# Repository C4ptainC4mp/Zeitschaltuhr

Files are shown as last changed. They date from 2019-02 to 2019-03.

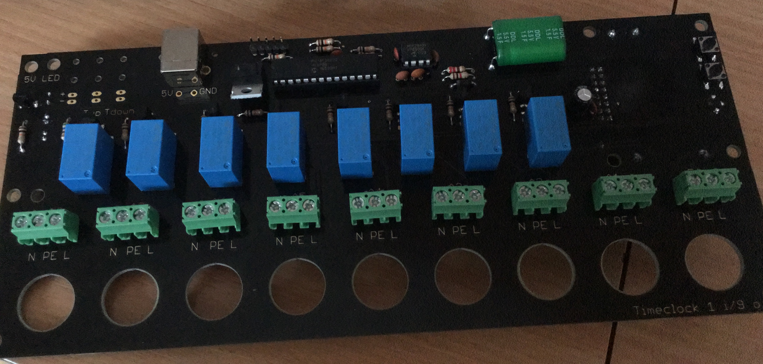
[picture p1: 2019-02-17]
demo/back.jpg

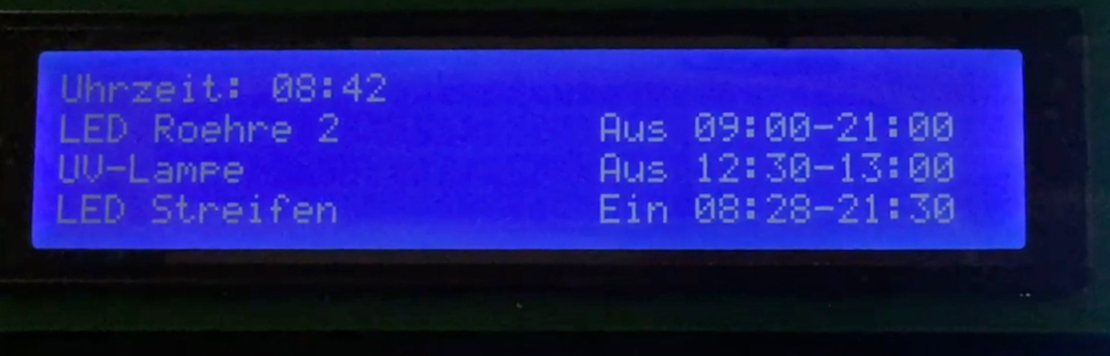
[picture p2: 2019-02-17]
demo/front_LCD.jpg

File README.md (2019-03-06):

# Zeitschaltuhr. 
time switch, supporting 8 AC outputs (10A max) and a 5V DC PWM output (2A max). 

This is a time switch supporting 8 AC outputs and a 5V DC PWM output. It also offers visualization with a LC-Display, configuration by a 2 button interface, a Real-Time-Clock(RTC) powered by a SuperCap and an on-board AC/DC power module.  

The combined switched power of all the AC outputs should not exceed 16A while a single output is limited to 10A. The DC PWM output is limited to 2A by the 15W IRM-15-5 AC/DC power module, more power output might be possible by selecting a better power module and power mosfet.

The current output status is presented by a 4x40 Character LC-Display. The first line shows the current time while the lines 2 to 4 show the outputs. Only 3 outputs are shown at once, it is possible to scroll trough the other outputs by pressing the scroll button.

In case of an blackout, the RTC is powered by a supercap for at least a week.  

It is possible to reconfigure the names and times by scrolling the target output to line 2 and pressing the select button.

The USB-B port is used to power the device while programming and debuging.

MCU: Microchip PIC18F26k22<br />
RTC: Microchip MCP 7940N (7940M also, but without backup power)<br />
LCD: ERM4004SBS-1 (2x KS0066 (HD44780 compatible))<br />

/demo includes a photo of the front and back side of the finished time switch.

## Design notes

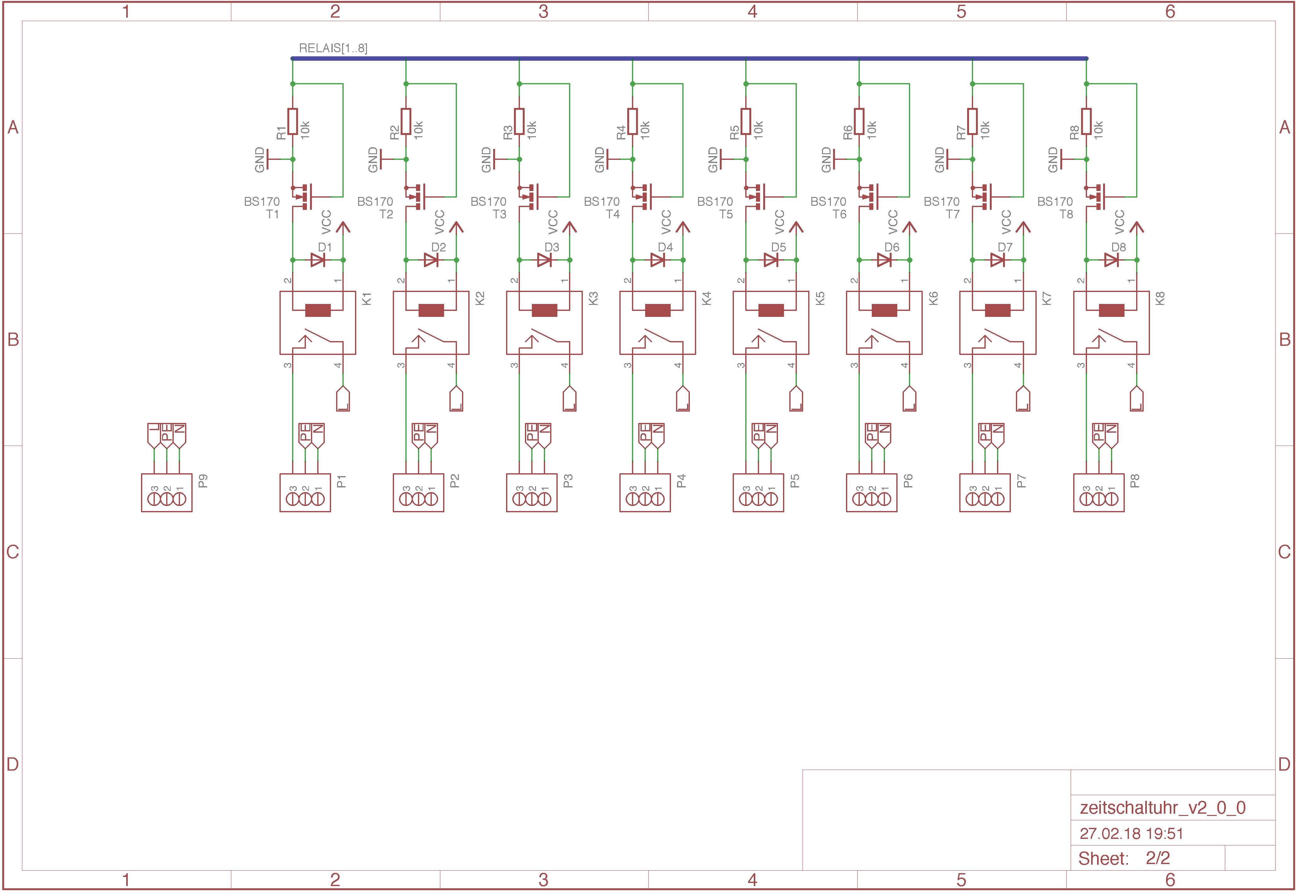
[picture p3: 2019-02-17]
Zeitschaltuhr V2.0.0/schematic_2.png

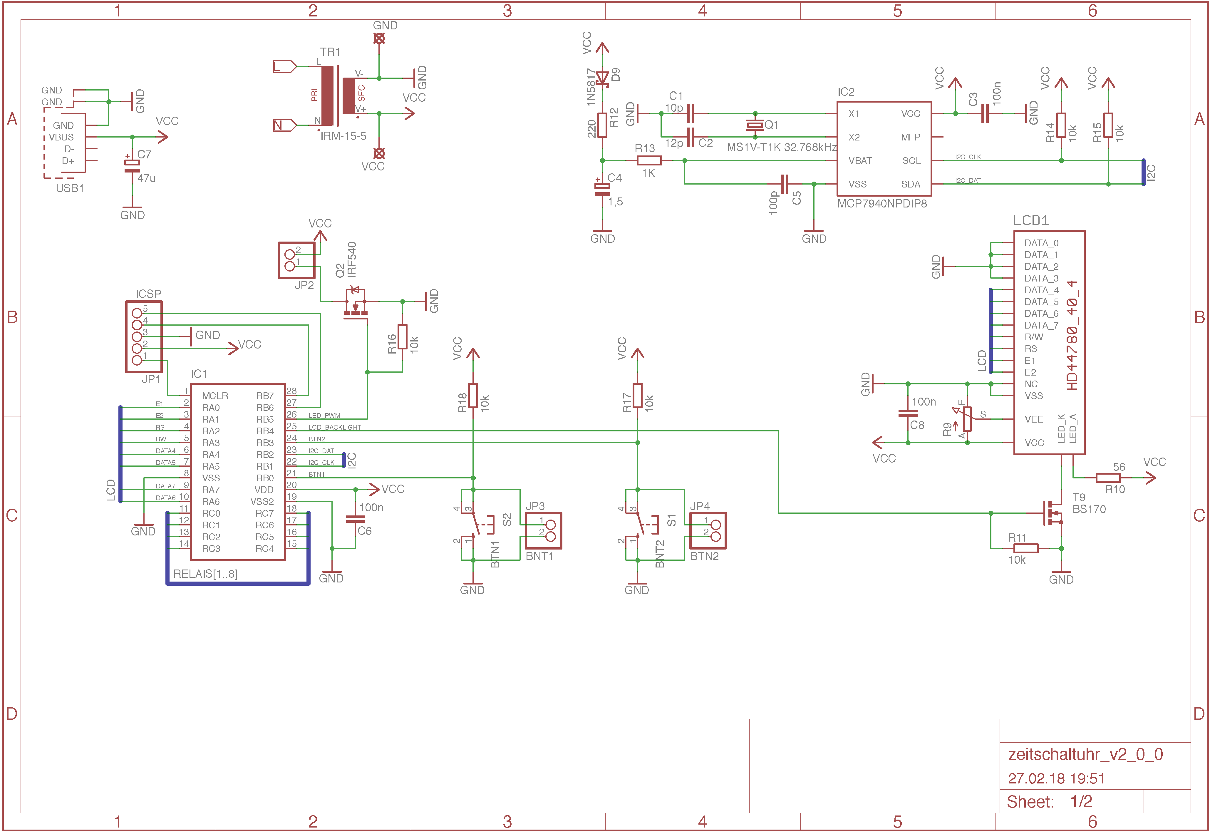
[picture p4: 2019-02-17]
Zeitschaltuhr V2.0.0/schematic_1.png

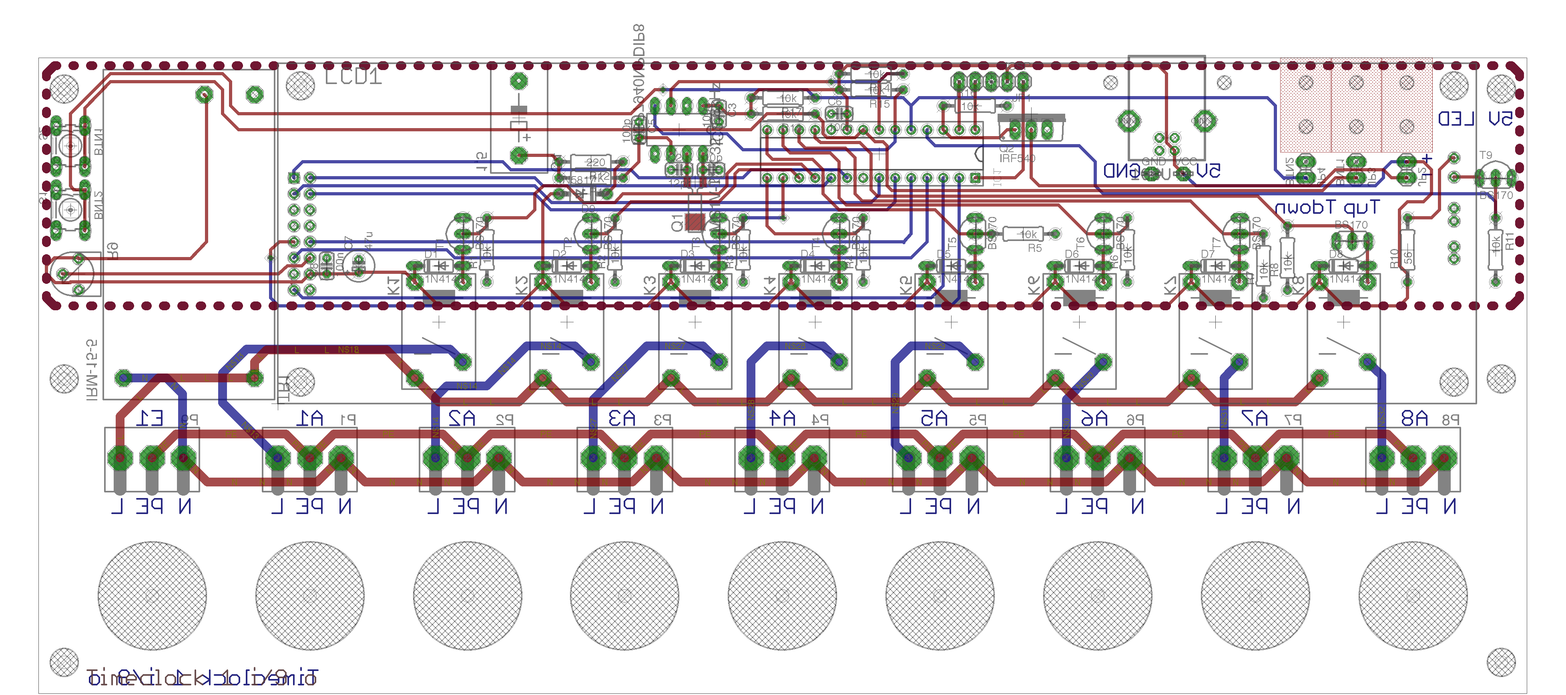
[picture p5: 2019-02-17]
Zeitschaltuhr V2.0.0/board.png

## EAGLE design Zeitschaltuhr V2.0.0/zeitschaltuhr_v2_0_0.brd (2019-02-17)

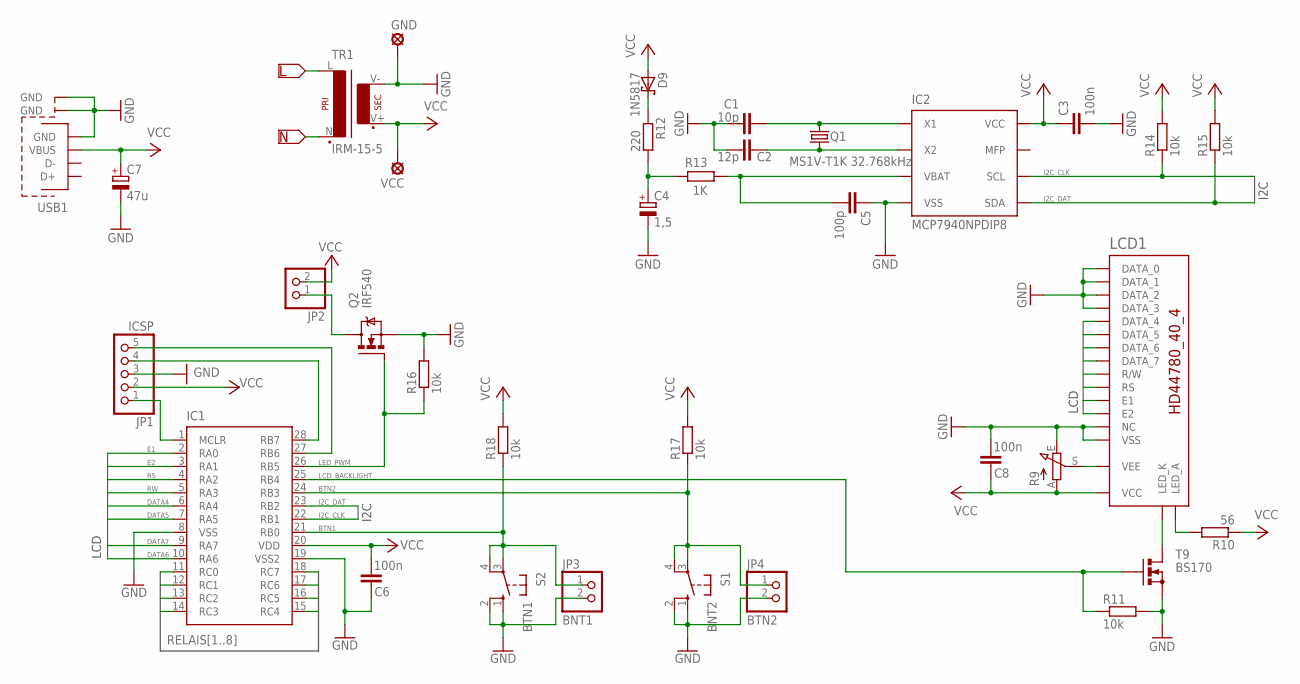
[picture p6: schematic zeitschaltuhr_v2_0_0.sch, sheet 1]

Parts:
C1: 10p; C025-024X044
C2: 12p; C025-024X044
C3, C6, C8: 100n; C025-024X044
C4: 1,5; DDL155S05F2CRRDAPZHORIZONTAL
C5: 100p; C025-024X044
C7: 47u; E2-5
D9: 1N5817; DO41-7
GND: LSP13
IC1: PIC18F26K22DIP28; DIP28
IC2: MCP7940NPDIP8; DIL8
JP1: ICSP; 1X05
JP2: PINHD-1X2; 1X02
JP3: BNT1; 1X02
JP4: BTN2; 1X02
LCD1: HD44780_4_40; HD44780_40_4
Q1: MS1V-T1K 32.768kHz; MS1V-T1K_SMD
Q2: IRF540; TO220BV
R9: 3306P-1-103
R10: 56; 0207/10
R11, R14, R15, R16, R17, R18: 10k; 0207/10
R12: 220; 0207/10
R13: 1K; 0207/10
S1: BNT2; B3F-10XX
S2: BTN1; B3F-10XX
T9: BS170; TO92-
TR1: IRM-15-5; IRM-15
USB1: USB_TYPE_B_THT; USB_TYPE_B_USB-B-S-RA
VCC: LSP13

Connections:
BTN1: IC1.21 (RB0), JP3.1, R18.1, S2.3, S2.4 (P1)
BTN2: IC1.24 (RB3), JP4.1, R17.1, S1.3, S1.4 (P1)
DATA4: IC1.6 (RA4), LCD1.4 (DATA_4)
DATA5: IC1.7 (RA5), LCD1.3 (DATA_5)
DATA6: IC1.10 (RA6), LCD1.2 (DATA_6)
DATA7: IC1.9 (RA7), LCD1.1 (DATA_7)
E1: IC1.2 (RA0), LCD1.9 (E1)
E2: IC1.3 (RA1), LCD1.15 (E2)
GND: C1.1, C2.1, C3.2, C4.-, C5.1, C6.1, C7.-, C8.2, GND.MP, IC1.8 (VSS), IC1.19 (VSS2), IC2.4 (VSS), JP1.3, JP3.2, JP4.2, LCD1.5 (DATA_3), LCD1.6 (DATA_2), LCD1.7 (DATA_1), LCD1.8 (DATA_0), LCD1.13 (VSS), LCD1.16 (NC), Q2.S, R9.E, R11.2, R16.2, S1.1 (S), S1.2 (S1), S2.1 (S), S2.2 (S1), T9.S, TR1.V-, USB1.GND@1 (GND), USB1.GND@2 (GND), USB1.GND@3 (GND); also elsewhere on the board
I2C_CLK: IC1.22 (RB1), IC2.6 (SCL), R14.1
I2C_DAT: IC1.23 (RB2), IC2.5 (SDA), R15.1
L: TR1.L; also elsewhere on the board
LCD_BACKLIGHT: IC1.25 (RB4), R11.1, T9.G
LED_A: LCD1.17 (LED_A), R10.2
LED_K: LCD1.18 (LED_K), T9.D
LED_PWM: IC1.26 (RB5), Q2.G, R16.1
N: TR1.N; also elsewhere on the board
unnamed: C1.2, IC2.1 (X1), Q1.1
unnamed: C2.2, IC2.2 (X2), Q1.2
unnamed: C4.+, R12.2, R13.2
unnamed: D9.C, R12.1
unnamed: C5.2, IC2.3 (VBAT), R13.1
unnamed: IC1.1 (MCLR), JP1.1
unnamed: IC1.28 (RB7), JP1.4
unnamed: IC1.27 (RB6), JP1.5
unnamed: JP2.1, Q2.D
RELAIS1: IC1.11 (RC0); also elsewhere on the board
RELAIS2: IC1.12 (RC1); also elsewhere on the board
RELAIS3: IC1.13 (RC2); also elsewhere on the board
RELAIS4: IC1.14 (RC3); also elsewhere on the board
RELAIS5: IC1.15 (RC4); also elsewhere on the board
RELAIS6: IC1.16 (RC5); also elsewhere on the board
RELAIS7: IC1.17 (RC6); also elsewhere on the board
RELAIS8: IC1.18 (RC7); also elsewhere on the board
RS: IC1.4 (RA2), LCD1.11 (RS)
RW: IC1.5 (RA3), LCD1.10 (R/W)
VCC: C3.1, C6.2, C7.+, C8.1, D9.A, IC1.20 (VDD), IC2.8 (VCC), JP1.2, JP2.2, LCD1.14 (VCC), R9.A, R10.1, R14.2, R15.2, R17.2, R18.2, TR1.V+, USB1.VBUS, VCC.MP; also elsewhere on the board
VEE: LCD1.12 (VEE), R9.S

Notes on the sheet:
I2C
LCD

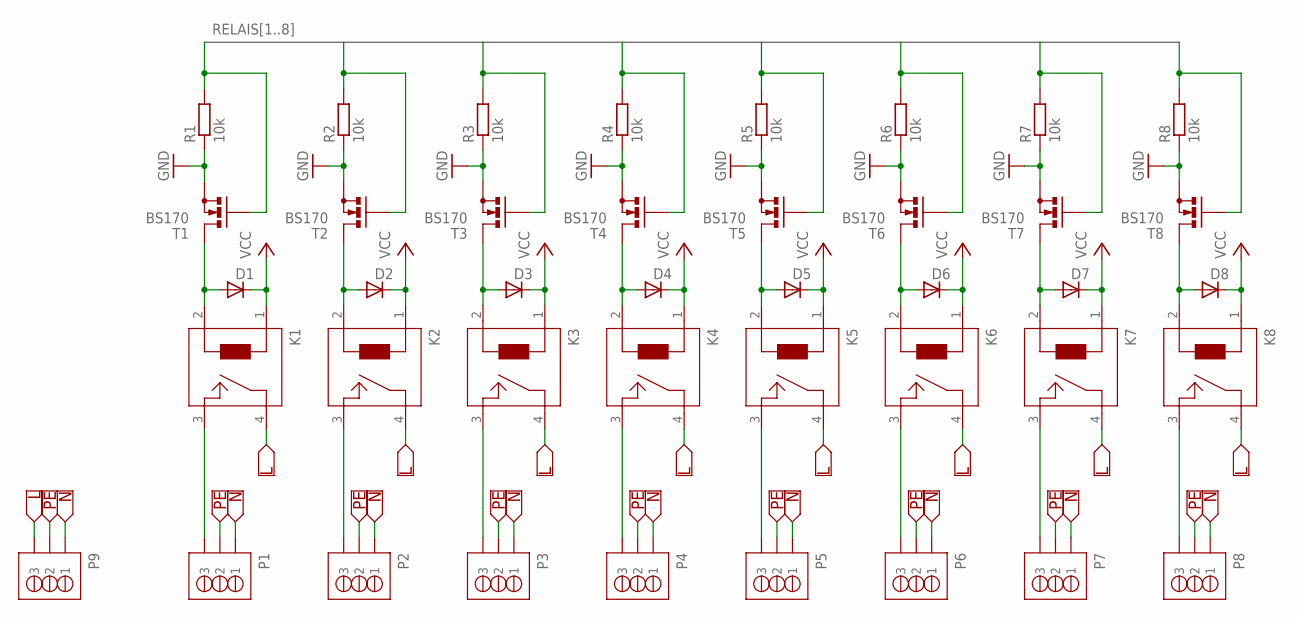
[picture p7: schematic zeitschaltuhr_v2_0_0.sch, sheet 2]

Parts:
D1, D2, D3, D4, D5, D6, D7, D8: 1N4148; DO35-7
K1, K2, K3, K4, K5, K6, K7, K8: OJE-SS-105HM,000
P1, P2, P3, P4, P5, P6, P7, P8, P9: TERMINAL_BLOCK_MB310-500M03
R1, R2, R3, R4, R5, R6, R7, R8: 10k; 0207/10
T1, T2, T3, T4, T5, T6, T7, T8: BS170; TO92-

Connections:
GND: R1.1, R2.1, R3.1, R4.1, R5.1, R6.1, R7.1, R8.1, T1.S, T2.S, T3.S, T4.S, T5.S, T6.S, T7.S, T8.S; also elsewhere on the board
L: K1.4, K2.4, K3.4, K4.4, K5.4, K6.4, K7.4, K8.4, P9.3; also elsewhere on the board
N: P1.1, P2.1, P3.1, P4.1, P5.1, P6.1, P7.1, P8.1, P9.1; also elsewhere on the board
unnamed: D1.A, K1.2, T1.D
unnamed: D2.A, K2.2, T2.D
unnamed: D3.A, K3.2, T3.D
unnamed: D4.A, K4.2, T4.D
unnamed: K1.3, P1.3
unnamed: K2.3, P2.3
unnamed: D5.A, K5.2, T5.D
unnamed: D6.A, K6.2, T6.D
unnamed: D7.A, K7.2, T7.D
unnamed: D8.A, K8.2, T8.D
unnamed: K3.3, P3.3
unnamed: K4.3, P4.3
unnamed: K5.3, P5.3
unnamed: K6.3, P6.3
unnamed: K7.3, P7.3
unnamed: K8.3, P8.3
PE: P1.2, P2.2, P3.2, P4.2, P5.2, P6.2, P7.2, P8.2, P9.2
RELAIS1: R1.2, T1.G; also elsewhere on the board
RELAIS2: R2.2, T2.G; also elsewhere on the board
RELAIS3: R3.2, T3.G; also elsewhere on the board
RELAIS4: R4.2, T4.G; also elsewhere on the board
RELAIS5: R5.2, T5.G; also elsewhere on the board
RELAIS6: R6.2, T6.G; also elsewhere on the board
RELAIS7: R7.2, T7.G; also elsewhere on the board
RELAIS8: R8.2, T8.G; also elsewhere on the board
VCC: D1.C, D2.C, D3.C, D4.C, D5.C, D6.C, D7.C, D8.C, K1.1, K2.1, K3.1, K4.1, K5.1, K6.1, K7.1, K8.1; also elsewhere on the board

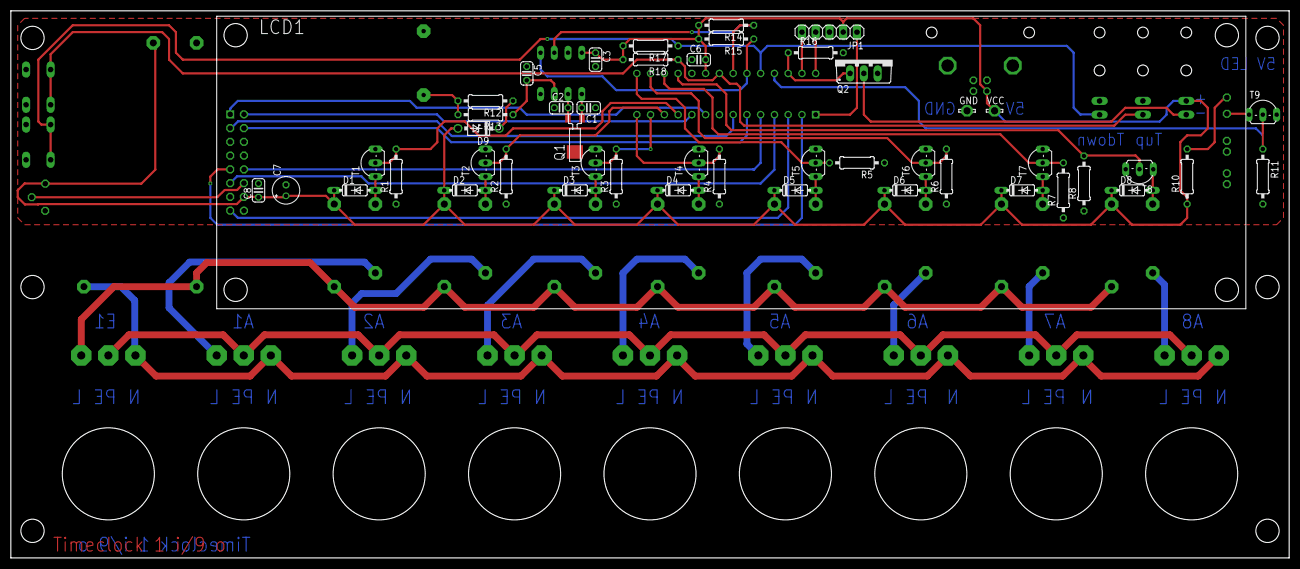
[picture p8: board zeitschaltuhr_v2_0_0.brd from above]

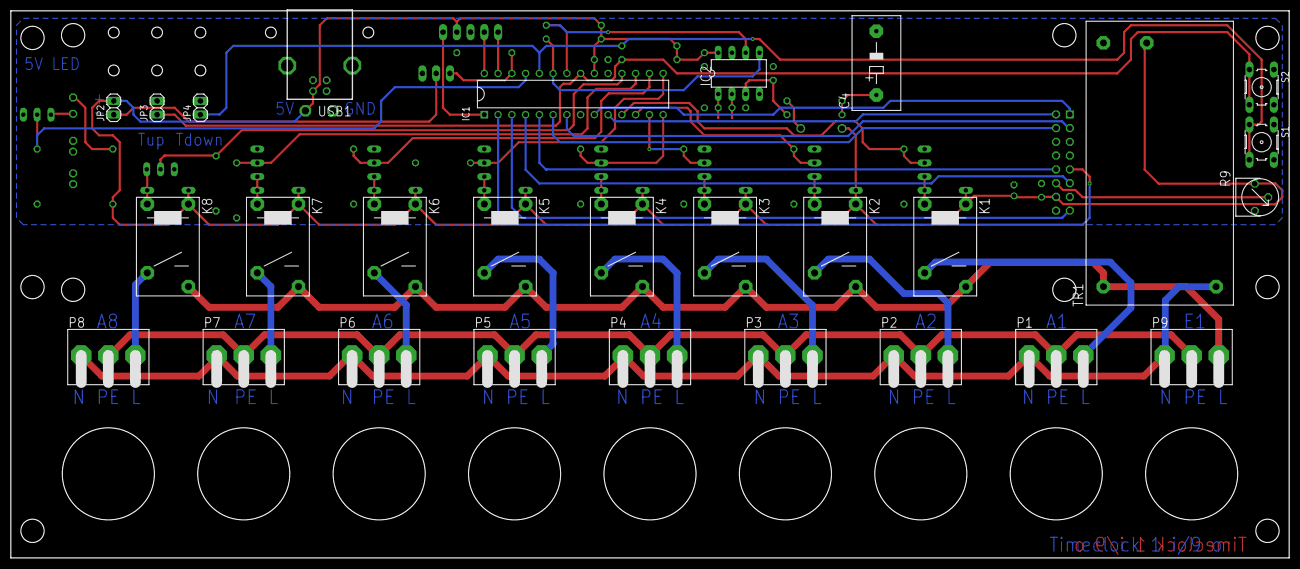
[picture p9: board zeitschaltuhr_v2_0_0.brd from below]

Board: 2 copper layers, 236.0 x 101.0 mm, 76 parts (28 on the bottom side), 55 nets.

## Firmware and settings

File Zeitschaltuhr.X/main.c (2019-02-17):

/**
  Generated Main Source File

  Company:
    Microchip Technology Inc.

  File Name:
    main.c

  Summary:
    This is the main file generated using PIC10 / PIC12 / PIC16 / PIC18 MCUs 

  Description:
    This header file provides implementations for driver APIs for all modules selected in the GUI.
    Generation Information :
        Product Revision  :  PIC10 / PIC12 / PIC16 / PIC18 MCUs  - 1.45
        Device            :  PIC18F26K22
        Driver Version    :  2.00
    The generated drivers are tested against the following:
        Compiler          :  XC8 1.35
        MPLAB             :  MPLAB X 3.40
*/

/*
    (c) 2016 Microchip Technology Inc. and its subsidiaries. You may use this
    software and any derivatives exclusively with Microchip products.

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
    IN NO EVENT WILL MICROCHIP BE LIABLE FOR ANY INDIRECT, SPECIAL, PUNITIVE,
    INCIDENTAL OR CONSEQUENTIAL LOSS, DAMAGE, COST OR EXPENSE OF ANY KIND
    WHATSOEVER RELATED TO THE SOFTWARE, HOWEVER CAUSED, EVEN IF MICROCHIP HAS
    BEEN ADVISED OF THE POSSIBILITY OR THE DAMAGES ARE FORESEEABLE. TO THE
    FULLEST EXTENT ALLOWED BY LAW, MICROCHIP'S TOTAL LIABILITY ON ALL CLAIMS IN
    ANY WAY RELATED TO THIS SOFTWARE WILL NOT EXCEED THE AMOUNT OF FEES, IF ANY,
    THAT YOU HAVE PAID DIRECTLY TO MICROCHIP FOR THIS SOFTWARE.

    MICROCHIP PROVIDES THIS SOFTWARE CONDITIONALLY UPON YOUR ACCEPTANCE OF THESE
    TERMS.
*/

#include "mcc_generated_files/mcc.h"
#include <xc.h>
#include <pic18f26k22.h>
#include <string.h>
#include <stdio.h>
#include <stdint.h>
#include <stdbool.h>
#include "lcd.h"
#include "mcp7940n.h"
#include "time.h"
#include "relay.h"

//BUILD CONFIGURATION
//#pragma warning disable(1404)

//DEFINES
#define RELAYSCOUNT         9
#define EEPROMSTARTADDRESS  0x00
#define ON                  1
#define OFF                 0
#define BACKLIGHTDURATION   10      //seconds
#define SYSTEM_TIME_LEN     5
#define NAMELENGTHMAX       22

//PROTOTYPES
void SetLEDBrightness(uint8_t percent);
void SetLCDBrightness(uint8_t percent);
void WriteDataEEPROM(void);
void ReadDataEEPROM(void);
void PrintSystemSetup(void);
void PrintListEntries(uint8_t listPosition);
void EditListEntry(uint8_t listPosition);
void PrintSystemTime(void);

//GLOBAL VARIABLES
relay relays[RELAYSCOUNT];
//time systemTime;
//FLAGS
unsigned uint8_t brightness = 50;

volatile bool btn0Flag = false;
volatile bool btn0LongPressFlag = false;
volatile bool btn1Flag = false;
volatile bool btn1LongPressFlag = false;
volatile bool msFlag = false;
volatile bool updateTimeFlag = false;
volatile bool flashFlag = false;
volatile uint8_t backlightCountdown = 30;
volatile time systemTime;
volatile uint8_t pwmSetPercent = 0;

const uint16_t pwmtable[101] =
{
    0,3,3,3,3,4,4,4,4,5,5,5,6,6,6,7,7,7,8,8,9,9,10,10,11,11,12,13,14,
    15,16,17,18,19,21,22,23,25,26,28,29,31,33,35,37,39,42,44,47,50,53,
    56,60,63,67,71,76,80,85,90,96,102,108,114,121,129,137,145,154,163,
    173,184,195,207,219,233,247,262,278,295,313,332,352,374,397,421,446,
    474,503,533,566,600,637,676,717,761,807,856,909,964,1023
};

void main(void) 
{
    uint8_t listPosition = 0;
    bool state = false;
    
    // Initialize the device
    SYSTEM_Initialize();
    
    LCD_Init();
    ReadDataEEPROM();
    
    systemTime.hr = 0;
    systemTime.min = 0;
    systemTime.sec = 0;
    
    relays[0].pin = 0;
    relays[1].pin = 1;
    relays[2].pin = 2;
    relays[3].pin = 3;
    relays[4].pin = 4;
    relays[5].pin = 5;
    relays[6].pin = 6;
    relays[7].pin = 7;
    relays[8].pin = 0;  //dummy pin
    
    relays[0].isPWM = false;
    relays[1].isPWM = false;
    relays[2].isPWM = false;
    relays[3].isPWM = false;
    relays[4].isPWM = false;
    relays[5].isPWM = false;
    relays[6].isPWM = false;
    relays[7].isPWM = false;
    relays[8].isPWM = true;
    
    SetLCDBrightness(brightness);
    SetLEDBrightness(0);
    
    //Boot screen
    LCD_string_line(1,(char*)("Hello! :)"));
    __delay_ms(1000);
    LCD_clear();
    
    INTERRUPT_PeripheralInterruptEnable();
    INTERRUPT_GlobalInterruptEnable();
    
    //This code initializes the switches to a default value, decomment, program
    /*
    relays[0].timeOn.hr = 8;
    relays[0].timeOn.min = 30;
    relays[0].timeOn.sec = 0;
    relays[0].timeOff.hr = 21;
    relays[0].timeOff.min = 30;
    relays[0].timeOff.sec = 0; 

    relays[1].timeOn.hr = 8;
    relays[1].timeOn.min = 35;
    relays[1].timeOn.sec = 0;
    relays[1].timeOff.hr = 21;
    relays[1].timeOff.min = 25;
    relays[1].timeOff.sec = 0; 
    
    relays[2].timeOn.hr = 8;
    relays[2].timeOn.min = 40;
    relays[2].timeOn.sec = 0;
    relays[2].timeOff.hr = 21;
    relays[2].timeOff.min = 20;
    relays[2].timeOff.sec = 0; 
    
    relays[3].timeOn.hr = 8;
    relays[3].timeOn.min = 45;
    relays[3].timeOn.sec = 0;
    relays[3].timeOff.hr = 21;
    relays[3].timeOff.min = 15;
    relays[3].timeOff.sec = 0; 
    
    relays[4].timeOn.hr = 8;
    relays[4].timeOn.min = 50;
    relays[4].timeOn.sec = 0;
    relays[4].timeOff.hr = 21;
    relays[4].timeOff.min = 10;
    relays[4].timeOff.sec = 0; 
    
    relays[5].timeOn.hr = 8;
    relays[5].timeOn.min = 55;
    relays[5].timeOn.sec = 0;
    relays[5].timeOff.hr = 21;
    relays[5].timeOff.min = 5;
    relays[5].timeOff.sec = 0; 
    
    relays[6].timeOn.hr = 9;
    relays[6].timeOn.min = 0;
    relays[6].timeOn.sec = 0;
    relays[6].timeOff.hr = 21;
    relays[6].timeOff.min = 0;
    relays[6].timeOff.sec = 0; 
    
    relays[7].timeOn.hr = 12;
    relays[7].timeOn.min = 30;
    relays[7].timeOn.sec = 0;
    relays[7].timeOff.hr = 13;
    relays[7].timeOff.min = 0;
    relays[7].timeOff.sec = 0; 
    
    relays[8].timeOn.hr = 8;
    relays[8].timeOn.min = 28;
    relays[8].timeOn.sec = 0;
    relays[8].timeOff.hr = 21;
    relays[8].timeOff.min = 30;
    relays[8].timeOff.sec = 0; 
    
    strcpy(relays[0].name,"Spot 1");
    strcpy(relays[1].name,"Spot 2");
    strcpy(relays[2].name,"Spot 3");
    strcpy(relays[3].name,"Spot 4");
    strcpy(relays[4].name,"Spot 5");
    strcpy(relays[5].name,"LED Roehre 1");
    strcpy(relays[6].name,"LED Roehre 2");
    strcpy(relays[7].name,"UV-Lampe");
    strcpy(relays[8].name,"LED Streifen");
    WriteDataEEPROM();
    while(1);*/
    
    INTERRUPT_GlobalInterruptEnable();
    
    //Check if the RTC is still active, or the user wants to do a reset.
    if(!MCP_CheckActive() || ((!BTN0) & (!BTN1)))
    {
        LCD_string_line(2,(char*)("Time deleted!"));
        __delay_ms(1000);
        while((!BTN0) & (!BTN1));
        btn0Flag = false;
        btn1Flag = false;
        
        PrintSystemSetup();
        MCP_WriteTime(systemTime);
        WriteDataEEPROM();  //save brightness
    }
    else
    {
        systemTime = MCP_ReadTime();
    }
    
    for(uint8_t i = 0; i < RELAYSCOUNT; i++)
    {
        if((state = RELAY_CheckTimes(&relays[i], systemTime)) != relays[i].active)
        {
            RELAY_Switch(&relays[i], state);
        }
    }
    
    LCD_clear();
    
    PrintSystemTime();
    PrintListEntries(listPosition);
  
    while(1)
    {   
        if(btn0Flag)
        {
            btn0Flag = false;
            SetLCDBrightness(brightness);
            
            listPosition++;
            if(listPosition == RELAYSCOUNT)
                listPosition = 0;
            
            PrintListEntries(listPosition);
        }
        
        if(btn1Flag)
        {
            btn1Flag = false;
            SetLCDBrightness(brightness);
            EditListEntry(listPosition);
            WriteDataEEPROM();
            LCD_clear();
            PrintSystemTime();
            PrintListEntries(listPosition);
        }
        
        if(updateTimeFlag)
        {   
            bool switched = false;
            updateTimeFlag = false;
            
            
            TMR0_StopTimer();
            time tempTime = MCP_ReadTime();
            TMR0_StartTimer();
            
            if(!TIME_equal(tempTime, systemTime))
            {
                systemTime = tempTime;
                PrintSystemTime();
            }

            for(uint8_t i = 0; i < RELAYSCOUNT; i++)
            {
                if((state = RELAY_CheckTimes(&relays[i], systemTime)) != relays[i].active)
                {
                    RELAY_Switch(&relays[i], state);
                    switched = true;
                }
            }
            
            if(switched) PrintListEntries(listPosition);
        }
        
        if(backlightCountdown == 0)
        {
            SetLCDBrightness(0);
        }
    }
}

void WriteDataEEPROM(void)
{
    uint16_t address = EEPROMSTARTADDRESS;
    for(uint8_t i = 0; i < RELAYSCOUNT; i++)
    {
        DATAEE_WriteByte(address++,relays[i].timeOn.hr);
        DATAEE_WriteByte(address++,relays[i].timeOn.min);
        DATAEE_WriteByte(address++,relays[i].timeOff.hr);
        DATAEE_WriteByte(address++,relays[i].timeOff.min);
    }
    
    for(uint8_t i = 0; i < RELAYSCOUNT; i++)
    {
        uint8_t j = 0;
        while((relays[i].name[j]) != '\0')
        {
            DATAEE_WriteByte(address++, relays[i].name[j]);
            j++;
        }
        DATAEE_WriteByte(address++, relays[i].name[j]);
    }
    
    DATAEE_WriteByte(address++, brightness);
    
}

void ReadDataEEPROM(void)
{
    unsigned char address = EEPROMSTARTADDRESS;
    for(uint8_t i = 0; i < RELAYSCOUNT; i++)
    {
        relays[i].timeOn.hr = DATAEE_ReadByte(address++);
        relays[i].timeOn.min = DATAEE_ReadByte(address++);
        relays[i].timeOff.hr = DATAEE_ReadByte(address++);
        relays[i].timeOff.min = DATAEE_ReadByte(address++);
    }
    
    for(uint8_t i = 0; i < RELAYSCOUNT; i++)
    {
        uint8_t j = 0;
        char c;
        while((c = DATAEE_ReadByte(address++)) != '\0')
        {
            relays[i].name[j] = c;
            j++;
        }
        relays[i].name[j] = c;
    }
    
    brightness = DATAEE_ReadByte(address++);
}

void SetLEDBrightness(uint8_t percent)
{
    if(percent == 0)
    {
        TRISBbits.TRISB5 = 1;
    }
    else
    {
        TRISBbits.TRISB5 = 0;
    }
    
    if(percent > 100)
    {
        percent = 100;
    }
    
    EPWM3_LoadDutyValue(pwmtable[percent]);
}

void SetLCDBrightness(uint8_t percent)
{   
    if(percent == 0)
    {
        TRISBbits.TRISB4 = 1;
    }
    else
    {
        TRISBbits.TRISB4 = 0;
    }
    
    if(percent > 100)
    {
        percent = 100;
    }
    
    EPWM1_LoadDutyValue(pwmtable[percent]);
}

void PrintSystemSetup(void)
{
    uint8_t pos = 0;
    char str[40];
    
    LCD_clear();
    LCD_string_line(1, (char*)"Uhrzeit:");
    
    while(pos < 4)
    {
        if(btn0Flag || (btn0LongPressFlag && msFlag))
        {
            msFlag = false;
            btn0Flag = false;
            if (pos == 0)
            {
                systemTime.hr++;
                if(systemTime.hr > 23)systemTime.hr = 0;
            }
            else if(pos == 3)
            {
                systemTime.min++;
                if(systemTime.min > 59) systemTime.min = 0;
            }  
        }
        
        if(btn1Flag)
        {
            btn1Flag = false;
            pos = (uint8_t)3 + pos;
        }
        
        sprintf(str,"%02d:%02d", systemTime.hr, systemTime.min);
        if(flashFlag && !btn0LongPressFlag)
        {
            str[pos] = '_';
            str[pos + (uint8_t)1] = '_';
        } 
        LCD_string_line(2, str); 
    }
    
    LCD_string_line(3, (char*)"Displayhelligkeit:");
    
    while(!btn1Flag)
    {
        if(btn0Flag || (btn0LongPressFlag && msFlag))
        {
            msFlag = false;
            btn0Flag = false;
            brightness++;
            if(brightness > 100) brightness = 0;
            SetLCDBrightness(brightness);
        }
        
        sprintf(str,"%3d", brightness);
        if(flashFlag && !btn0LongPressFlag)
        {
            str[0] = '_';
            str[1] = '_';
            str[2] = '_';
        } 
        LCD_string_line(4, str); 
    }
    
    btn1Flag = false;
}

void PrintListEntries(uint8_t listPosition)
{
    char str1[41];
    char str2[41];
    char str3[41];
    
    if(relays[listPosition].active) 
    {
        sprintf(str1,"%-22s Ein %02d:%02d-%02d:%02d   ",relays[listPosition].name, relays[listPosition].timeOn.hr, relays[listPosition].timeOn.min, relays[listPosition].timeOff.hr, relays[listPosition].timeOff.min);
    }
    else
    {
        sprintf(str1,"%-22s Aus %02d:%02d-%02d:%02d   ",relays[listPosition].name, relays[listPosition].timeOn.hr, relays[listPosition].timeOn.min, relays[listPosition].timeOff.hr, relays[listPosition].timeOff.min);
    }
    LCD_string_line(2,str1);
    
    listPosition++;
    if(listPosition == RELAYSCOUNT)
    {
        listPosition -= RELAYSCOUNT;
    }
    if(relays[listPosition].active) 
    {
        sprintf(str2,"%-22s Ein %02d:%02d-%02d:%02d   ",relays[listPosition].name, relays[listPosition].timeOn.hr, relays[listPosition].timeOn.min, relays[listPosition].timeOff.hr, relays[listPosition].timeOff.min);
    }    
    else
    {
        sprintf(str2,"%-22s Aus %02d:%02d-%02d:%02d   ",relays[listPosition].name, relays[listPosition].timeOn.hr, relays[listPosition].timeOn.min, relays[listPosition].timeOff.hr, relays[listPosition].timeOff.min);
    }
    LCD_string_line(3,str2);
    listPosition++;
    if(listPosition == RELAYSCOUNT)
    {
        listPosition -= RELAYSCOUNT;
    }
    
    if(relays[listPosition].active) 
    {
        sprintf(str3,"%-22s Ein %02d:%02d-%02d:%02d   ",relays[listPosition].name, relays[listPosition].timeOn.hr, relays[listPosition].timeOn.min, relays[listPosition].timeOff.hr, relays[listPosition].timeOff.min);
    }
    else
    {
        sprintf(str3,"%-22s Aus %02d:%02d-%02d:%02d   ",relays[listPosition].name, relays[listPosition].timeOn.hr, relays[listPosition].timeOn.min, relays[listPosition].timeOff.hr, relays[listPosition].timeOff.min);
    }
    
    LCD_string_line(4,str3);
}

void EditListEntry(uint8_t listPosition)
{
    char str[41];
    uint8_t pos = 0;
    char c[] = " abcdefghijklmnopqrstuvwxyzABCDEFGHIJKLMNOPQRSTUVWXYZ0123456789-";
    uint8_t i = 0;
    
    LCD_clear();
    
    while(pos < 22)
    {
        sprintf(str,"%-22s %02d:%02d-%02d:%02d",relays[listPosition].name, relays[listPosition].timeOn.hr, relays[listPosition].timeOn.min, relays[listPosition].timeOff.hr, relays[listPosition].timeOff.min);
        
        if(btn0Flag || (btn0LongPressFlag && msFlag))
        {
            msFlag = false;
            btn0Flag = false;
            i++;
            if(i >= strlen(c))i = 0;
            relays[listPosition].name[pos] = c[i];
        }
        
        if(btn1Flag)
        {
            btn1Flag = false;
            int j = 0;
            for(; j < strlen(c); j++)
            {
                if(relays[listPosition].name[pos] == c[j])
                {
                    break;
                }
            }
            if(j == strlen(c))
            {
                relays[listPosition].name[pos] = ' ';
            }
            
            pos++;
            i = 0;
        }
        
        if(flashFlag && !btn0LongPressFlag)
        {
            str[pos] = '_';
        } 
        
        LCD_string_line(2, str); 
    }
    
    relays[listPosition].name[NAMELENGTHMAX] = '\0';
    
    pos = 0;
    
    while(pos < 10)
    {       
        if(btn0Flag || (btn0LongPressFlag && msFlag))
        {
            msFlag = false;
            btn0Flag = false;
            switch(pos)
            {
                case 0:
                    relays[listPosition].timeOn.hr++;
                    if(relays[listPosition].timeOn.hr > 23)relays[listPosition].timeOn.hr = 0;
                    break;
                case 3:
                    relays[listPosition].timeOn.min++;
                    if(relays[listPosition].timeOn.min > 59) relays[listPosition].timeOn.min = 0;
                    break;
                case 6:
                    relays[listPosition].timeOff.hr++;
                    if(relays[listPosition].timeOff.hr > 23)relays[listPosition].timeOff.hr = 0;
                    break;
                case 9:
                    relays[listPosition].timeOff.min++;
                    if(relays[listPosition].timeOff.min > 59) relays[listPosition].timeOff.min = 0;
                    break;
                default:
                    break;
            }
        }
        
        if(btn1Flag)
        {
            btn1Flag = false;
            pos = (uint8_t)(pos + 3);
        }
        
        sprintf(str,"%-22s %02d:%02d-%02d:%02d",relays[listPosition].name, relays[listPosition].timeOn.hr, relays[listPosition].timeOn.min, relays[listPosition].timeOff.hr, relays[listPosition].timeOff.min);
        
        if(flashFlag && !btn0LongPressFlag)
        {
            str[(uint8_t)23 + pos] = '_';
            str[(uint8_t)24 + pos] = '_';
        }
        
        LCD_string_line(2, str); 
    }
}

void PrintSystemTime(void)
{
    char str[41];
    sprintf(str,"Uhrzeit: %02d:%02d%26s", systemTime.hr, systemTime.min,"");
    LCD_string_line(1,str);
}

/**
 End of File
*/

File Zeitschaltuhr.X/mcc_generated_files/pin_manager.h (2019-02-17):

/**
  @Generated Pin Manager Header File

  @Company:
    Microchip Technology Inc.

  @File Name:
    pin_manager.h

  @Summary:
    This is the Pin Manager file generated using MPLAB(c) Code Configurator

  @Description:
    This header file provides implementations for pin APIs for all pins selected in the GUI.
    Generation Information :
        Product Revision  :  MPLAB(c) Code Configurator - 4.26
        Device            :  PIC18F26K22
        Version           :  1.01
    The generated drivers are tested against the following:
        Compiler          :  XC8 1.35
        MPLAB             :  MPLAB X 3.40

    Copyright (c) 2013 - 2015 released Microchip Technology Inc.  All rights reserved.

    Microchip licenses to you the right to use, modify, copy and distribute
    Software only when embedded on a Microchip microcontroller or digital signal
    controller that is integrated into your product or third party product
    (pursuant to the sublicense terms in the accompanying license agreement).

    You should refer to the license agreement accompanying this Software for
    additional information regarding your rights and obligations.

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
*/


#ifndef PIN_MANAGER_H
#define PIN_MANAGER_H

#define INPUT   1
#define OUTPUT  0

#define HIGH    1
#define LOW     0

#define ANALOG      1
#define DIGITAL     0

#define PULL_UP_ENABLED      1
#define PULL_UP_DISABLED     0

// get/set IO_RA0 aliases
#define IO_RA0_TRIS               TRISAbits.TRISA0
#define IO_RA0_LAT                LATAbits.LATA0
#define IO_RA0_PORT               PORTAbits.RA0
#define IO_RA0_ANS                ANSELAbits.ANSA0
#define IO_RA0_SetHigh()            do { LATAbits.LATA0 = 1; } while(0)
#define IO_RA0_SetLow()             do { LATAbits.LATA0 = 0; } while(0)
#define IO_RA0_Toggle()             do { LATAbits.LATA0 = ~LATAbits.LATA0; } while(0)
#define IO_RA0_GetValue()           PORTAbits.RA0
#define IO_RA0_SetDigitalInput()    do { TRISAbits.TRISA0 = 1; } while(0)
#define IO_RA0_SetDigitalOutput()   do { TRISAbits.TRISA0 = 0; } while(0)
#define IO_RA0_SetAnalogMode()  do { ANSELAbits.ANSA0 = 1; } while(0)
#define IO_RA0_SetDigitalMode() do { ANSELAbits.ANSA0 = 0; } while(0)

// get/set IO_RA1 aliases
#define IO_RA1_TRIS               TRISAbits.TRISA1
#define IO_RA1_LAT                LATAbits.LATA1
#define IO_RA1_PORT               PORTAbits.RA1
#define IO_RA1_ANS                ANSELAbits.ANSA1
#define IO_RA1_SetHigh()            do { LATAbits.LATA1 = 1; } while(0)
#define IO_RA1_SetLow()             do { LATAbits.LATA1 = 0; } while(0)
#define IO_RA1_Toggle()             do { LATAbits.LATA1 = ~LATAbits.LATA1; } while(0)
#define IO_RA1_GetValue()           PORTAbits.RA1
#define IO_RA1_SetDigitalInput()    do { TRISAbits.TRISA1 = 1; } while(0)
#define IO_RA1_SetDigitalOutput()   do { TRISAbits.TRISA1 = 0; } while(0)
#define IO_RA1_SetAnalogMode()  do { ANSELAbits.ANSA1 = 1; } while(0)
#define IO_RA1_SetDigitalMode() do { ANSELAbits.ANSA1 = 0; } while(0)

// get/set IO_RA2 aliases
#define IO_RA2_TRIS               TRISAbits.TRISA2
#define IO_RA2_LAT                LATAbits.LATA2
#define IO_RA2_PORT               PORTAbits.RA2
#define IO_RA2_ANS                ANSELAbits.ANSA2
#define IO_RA2_SetHigh()            do { LATAbits.LATA2 = 1; } while(0)
#define IO_RA2_SetLow()             do { LATAbits.LATA2 = 0; } while(0)
#define IO_RA2_Toggle()             do { LATAbits.LATA2 = ~LATAbits.LATA2; } while(0)
#define IO_RA2_GetValue()           PORTAbits.RA2
#define IO_RA2_SetDigitalInput()    do { TRISAbits.TRISA2 = 1; } while(0)
#define IO_RA2_SetDigitalOutput()   do { TRISAbits.TRISA2 = 0; } while(0)
#define IO_RA2_SetAnalogMode()  do { ANSELAbits.ANSA2 = 1; } while(0)
#define IO_RA2_SetDigitalMode() do { ANSELAbits.ANSA2 = 0; } while(0)

// get/set IO_RA3 aliases
#define IO_RA3_TRIS               TRISAbits.TRISA3
#define IO_RA3_LAT                LATAbits.LATA3
#define IO_RA3_PORT               PORTAbits.RA3
#define IO_RA3_ANS                ANSELAbits.ANSA3
#define IO_RA3_SetHigh()            do { LATAbits.LATA3 = 1; } while(0)
#define IO_RA3_SetLow()             do { LATAbits.LATA3 = 0; } while(0)
#define IO_RA3_Toggle()             do { LATAbits.LATA3 = ~LATAbits.LATA3; } while(0)
#define IO_RA3_GetValue()           PORTAbits.RA3
#define IO_RA3_SetDigitalInput()    do { TRISAbits.TRISA3 = 1; } while(0)
#define IO_RA3_SetDigitalOutput()   do { TRISAbits.TRISA3 = 0; } while(0)
#define IO_RA3_SetAnalogMode()  do { ANSELAbits.ANSA3 = 1; } while(0)
#define IO_RA3_SetDigitalMode() do { ANSELAbits.ANSA3 = 0; } while(0)

// get/set IO_RA4 aliases
#define IO_RA4_TRIS               TRISAbits.TRISA4
#define IO_RA4_LAT                LATAbits.LATA4
#define IO_RA4_PORT               PORTAbits.RA4
#define IO_RA4_SetHigh()            do { LATAbits.LATA4 = 1; } while(0)
#define IO_RA4_SetLow()             do { LATAbits.LATA4 = 0; } while(0)
#define IO_RA4_Toggle()             do { LATAbits.LATA4 = ~LATAbits.LATA4; } while(0)
#define IO_RA4_GetValue()           PORTAbits.RA4
#define IO_RA4_SetDigitalInput()    do { TRISAbits.TRISA4 = 1; } while(0)
#define IO_RA4_SetDigitalOutput()   do { TRISAbits.TRISA4 = 0; } while(0)

// get/set IO_RA5 aliases
#define IO_RA5_TRIS               TRISAbits.TRISA5
#define IO_RA5_LAT                LATAbits.LATA5
#define IO_RA5_PORT               PORTAbits.RA5
#define IO_RA5_ANS                ANSELAbits.ANSA5
#define IO_RA5_SetHigh()            do { LATAbits.LATA5 = 1; } while(0)
#define IO_RA5_SetLow()             do { LATAbits.LATA5 = 0; } while(0)
#define IO_RA5_Toggle()             do { LATAbits.LATA5 = ~LATAbits.LATA5; } while(0)
#define IO_RA5_GetValue()           PORTAbits.RA5
#define IO_RA5_SetDigitalInput()    do { TRISAbits.TRISA5 = 1; } while(0)
#define IO_RA5_SetDigitalOutput()   do { TRISAbits.TRISA5 = 0; } while(0)
#define IO_RA5_SetAnalogMode()  do { ANSELAbits.ANSA5 = 1; } while(0)
#define IO_RA5_SetDigitalMode() do { ANSELAbits.ANSA5 = 0; } while(0)

// get/set IO_RA6 aliases
#define IO_RA6_TRIS               TRISAbits.TRISA6
#define IO_RA6_LAT                LATAbits.LATA6
#define IO_RA6_PORT               PORTAbits.RA6
#define IO_RA6_SetHigh()            do { LATAbits.LATA6 = 1; } while(0)
#define IO_RA6_SetLow()             do { LATAbits.LATA6 = 0; } while(0)
#define IO_RA6_Toggle()             do { LATAbits.LATA6 = ~LATAbits.LATA6; } while(0)
#define IO_RA6_GetValue()           PORTAbits.RA6
#define IO_RA6_SetDigitalInput()    do { TRISAbits.TRISA6 = 1; } while(0)
#define IO_RA6_SetDigitalOutput()   do { TRISAbits.TRISA6 = 0; } while(0)
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
